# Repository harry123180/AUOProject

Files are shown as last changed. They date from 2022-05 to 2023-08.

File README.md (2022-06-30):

# AUOProject

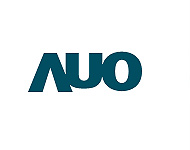
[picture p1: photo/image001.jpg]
   

## 系統架構  
## 如果你想快速開始並設置請參閱[Quick Start Guide](document/Quick%20Start%20Guide.md)

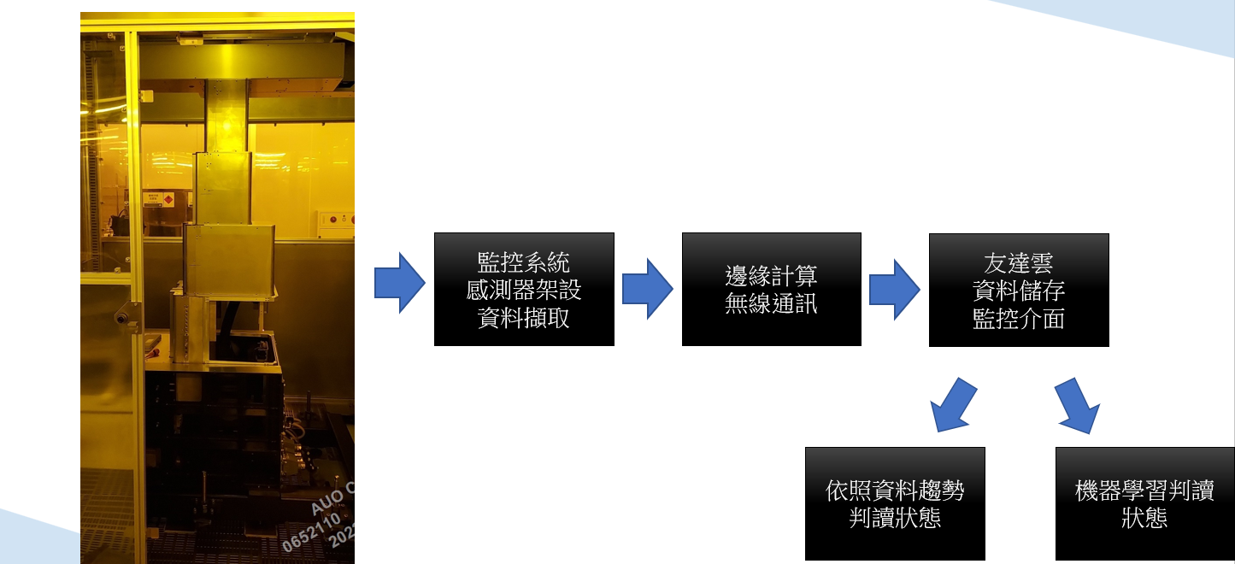
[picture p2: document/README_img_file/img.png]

* 目標開發一個應用於晶圓搬運Robo之Z軸鋼帶壽命監控系統。
* 其系統架構可分成三個部分
  * ## [上游端](document/上游端.md)
    > 該部分主要是感測器、微處理器整合之模組
  * ## [中遊端](document/中遊端.md)
    >該部分主要是基於微處理器上開發整合資料擷取、資料處理、邊緣計算得出特徵指標、無線傳輸等功能
  * ## [下游端](document/下游端.md)
    >該部分主要是終端顯示、資料儲存、人工智慧判斷的部分
* [邊緣計算部分C語言實現API](document/API.md)
* [裝設指南-硬體篇](document/上游端.md)
* [裝設指南-Windows主機篇]
* [裝設指南-InfluxDB篇](document/Install%20InfluxDB%20windows.md)
* [裝設指南-Grafana篇](document/Install%20Grafana%20windows.md)

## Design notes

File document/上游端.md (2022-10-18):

# 上游端    
監控模組3D外觀   
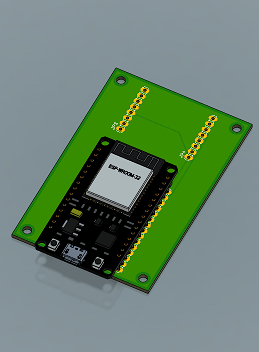
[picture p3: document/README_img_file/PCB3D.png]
  

PCB Layout  
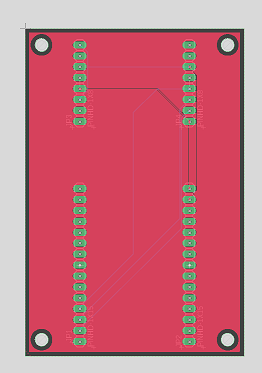
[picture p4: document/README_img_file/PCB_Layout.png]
  
PCB 原理圖  
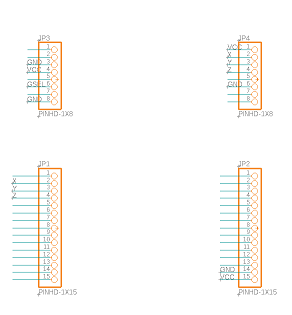
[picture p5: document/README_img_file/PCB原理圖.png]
  
#I/O table  
## FXLN8371Q
|  Pin | Name  | Eescription  | I/O  |
|  ----  | ----  | ----  | ----  |
| 1  | BYP | 內部穩壓器輸出電容連接 |Output |
| 2  | VDD | 電源電壓3.3V |Power |
| 3  | ST | 自我測試<br> • 當 ST 引腳為邏輯高電平時，加速度計進入自檢模式。 <br> • 當 ST 引腳為邏輯低電平時，加速度計進入正常工作模式。 |Input |
| 4  | EN | 電源使能引腳<br>• 當 EN 引腳為邏輯低電平時，加速度計關閉，電流最小<br>• 當 EN 引腳為邏輯高電平時，加速度計功能齊全。 |Input |
| 5  | g-Select | 滿量程範圍選擇： <br>對於部件號 FXLN8361QR1 和 FXLN8371QR1： <br>• 當g-select 引腳為邏輯低電平時，加速度計處於±8 g 模式 <br>• 當g-select 引腳為邏輯高電平時，加速度計處於±2 g 模式<br>對於部件號 FXLN8362QR1 和 FXLN8372QR1：<br>• 當g-select 引腳為邏輯低時，加速度計處於±16 g 模式<br>• 當g-select 引腳為邏輯高電平時，加速度計處於±4 g 模式 |Input |
| 6  | GND | Ground |Ground |
| 7  | GND | Ground |Ground |
| 8  | Z<sub>OUT | Z-axis analog output |Output |
| 9  | Y<sub>OUT | Y-axis analog output |Output |
| 10  | X<sub>OUT | X-axis analog output |Output |
| 11  | NC | 無內部連接，可懸空或連接到 GND |— |
| 12  | NC | 無內部連接，可懸空或連接到 GND |— |
| 13  | NC | 無內部連接，可懸空或連接到 GND |— |  

#FXLN8371Q特性  

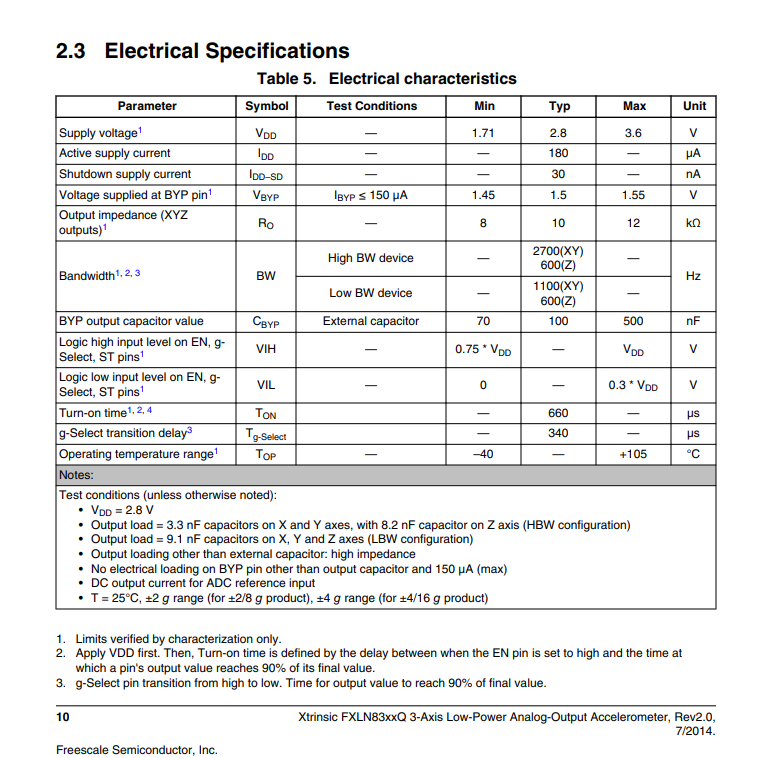
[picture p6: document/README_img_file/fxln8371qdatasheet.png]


##Connection  

|  FXLN8371Q | ESP32  |
|  ----  | ----  |
| X<sub>OUT  | GPIO36 |
| Y<sub>OUT  | GPIO39 |
| Y<sub>OUT  | GPIO34 |
#以下為加速規的重要特性指標
## 靈敏度
> ```X、Y、Z Sensitivity``` : 54mV/g
## 頻寬
|  FXLN8371Q   | BandWidth  |
|  ----  | ----  | 
| X Axis  | 2700Hz |
| Y Axis  | 2700Hz |
| Y Axis  |  600Hz |

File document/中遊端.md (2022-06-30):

#中遊端 MCU EdgeComputing
## 中遊端工作任務主要如下
> * 負責上游感測器的資料擷取
> * 撈取到資料進行邊緣運算
> * 將資料特徵傳輸出去

在本計畫選用ESP32作為中遊節點計算與傳輸的載體
## ESP32-WROOM介紹
|  項目 | 規格  |
|  ----  | ----  |
| 工作電壓  | 3.0V~3.6V |
| 工作電流  | 平均:80mA |
| 供電電流  | 最小:500mA |
| 工作溫度  | -40&deg;C~+85&deg;C|
|封裝尺寸| 18mm &times; 25.5mm &times; 3.1mm|
| Wi-Fi | 支持802.11 b/g/n 協議|
## ESP32-WROOM功能方塊圖
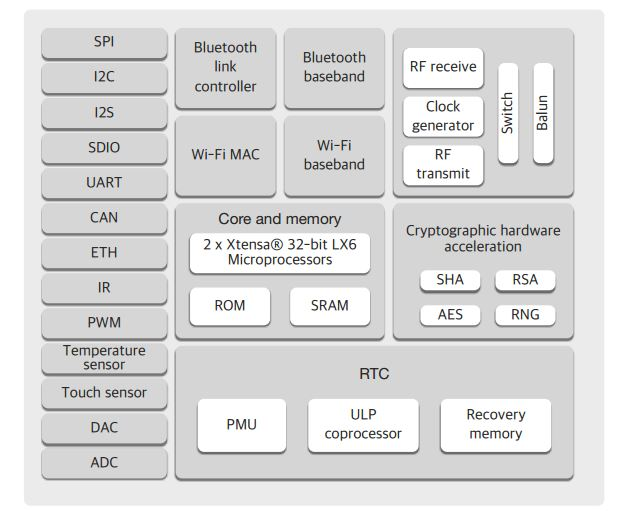
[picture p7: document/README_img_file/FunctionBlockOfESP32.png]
FunctionBlockOfESP32

## 本專案設計遇到注意事項
* ESP32上共有兩個12bit的SARADC分別為ADC1與ADC2
* 其中Wi-Fi也就是無線傳輸功能與ADC2互斥，也就是同時只能運行一個
* 因此ESP32在選擇讀取類比訊號時必須避開ADC2腳位。
* 根據現場量測數據來看，採樣速度須達到5KHz以上，才可以看到我們希望看到的頻率範圍
* 同時對三軸進行5KHz以上速度採樣及FFT轉換，相當重的計算任務
## FreeRTOS對ESP32有良好支援
### [什麼是RTOS?](https://great-vole-c2e.notion.site/ESP32-with-RTOS-08773e8b050648a0af60a7a117fe66ee)一文中有提到，該專案為了解決採樣、邊緣計算、MQTT無線傳輸在MCU上並行執行，採用RTOS架構來編程

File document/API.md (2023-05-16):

# EdgeComputing.h Libary API Document 
## 以下對於本專案使用之指標數學公式進行說明
### ESP對類比式加速規採樣
> ESP的ADC是SARADC具有12bit的解析度(**resolution**)  
> 加速規輸出一電壓訊號時，經由Analog/Digital轉換之後其轉換公式如下  
> $$acceleration = \frac{workvolt}{resolution}*(Numerical-bias)\div sensitivity$$  
> + acceleration: 轉換之加速度值 單位 (g) or (m/s^2) 
> + workvolt: 為ESP32的工作電壓 為3.3V
> + resolution:為ESP32 A/D解析度 12bit=4096
> + Numberical:採樣之後的數值訊號 0~4095之間
> + bias:加速規在0g情況下的數值偏壓
> + sensitivity:加速規的靈敏度 單位 mV/g
### 時域方面
* **平均值**原始數據之平均數值。
>$$\mathrm{Mean}=\frac{1}{n} \sum_{i=1}^{n} x_{i}$$
* **方均根**:原始數據之方均根值，評估訊號振幅。

>$$\mathrm{RMS}=\sqrt{\frac{1}{n} \sum_{i=1}^{n} x_{i}^{2}}$$

* **峰度**:第四中央慣性矩，評估時域訊號中高頻訊號的比例。
>$$ \text { Kurtosis }=\frac{1}{n} \frac{\sum_{i=1}^{n}\left(x_{i}-\mu\right)^{4}}{\sigma^{4}} $$

* **標準差**原始數據之標準差，代表扣除平均值的訊號振幅。
>$$\text { std }=\sqrt{\frac{\sum_{i=1}^{n}\left(x_{i}-\mu\right)^{2}}{n-1}} $$
### 頻域方面
* **頻譜強度總和**:透過在有興趣頻段對PSD做積分即可獲得總功率。
>$$ \text { Total power }=\int_{0}^{f_{s} / 2} S(f) d f $$
* **頻譜強度比例(Ratio of power,ROP)**:此方法主要應用頻寬較大之感測器，頻域訊號依照頻率分段，並以頻段內的總頻譜強度除以頻譜強度總和即為該頻段之頻譜強度比例。
>$$ \text { ROP }=\frac{\int_{f_{1}}^{f_{2}} S(f) d f}{\text { Total power }} $$

### 在ESP32 Program 邊緣計算部分過於複雜，因此獨立編寫一個庫，方便管理及說明
* 整個EdgeComputing庫裡面共有兩個物件可以宣告
1. 第一個是```Func```
2. 第二個是```Computer```

以下是使用範本

```
#include "EdgeComputing.h"
Computer 物件名;
物件名.API();
```
###```Func```為測試用物件，單純實現加法庫。

### ```Computer```為管理指標運算的物件，裡面API說明如下:
> ```float Mean(float* Time_Array);```
> * 輸入參數: 
>>```Time_Array```:時域數據陣列
> * 回傳:
>>```Mean```:平均數

> ```float Std(float* Time_Array,float avg);```
> * 輸入參數: 
>>```Time_Array``` :時域數據陣列  
>>```avg```: 時域數據陣列之平均值
> * 回傳:
>> ```std```:時域數據陣列之標準差

> ```float RMS(float Time_Array);```
> * 輸入參數:
>>```Time_Array```:時域數據陣列
> * 回傳:
>> ```rms```:時域數據陣列之方均根值

> ``` float Kurtosis(float Time_Array,float avg,float std);```
> * 輸入參數:
>> ```Time_Array```:時域數據陣列  
>> ```avg```: 時域數據陣列之平均值  
>> ```std```: 時域數據陣列之標準差
> * 回傳:
>> ```kurtosis```: 時域數據陣列之峰度指標

> ```float Total_Power(float* Freq_Array);```
> * 輸入參數:
>> ```Freq_Array```:經過FFT之後的頻域數據陣列
> * 回傳:
>> ```TP```: 整個頻譜的功率和

> ```float ROP(float* Freq_Array,int Freq_min,int Freq_max,float TP);```
> * 輸入參數:
>> ```Freq_Array```:經過FFT之後的頻域數據陣列
>> ```Freq_min```:有興趣頻段的最小
>> ```Freq_max```:有興趣頻段的最大
> * 回傳:
>> ```rop```: 頻譜強度比例

> ```float Mean_2D(float** Time_Array,float* mean_2d);```
> * 輸入參數:
>> ```Time_Array```:二維時域數據[軸][採樣buffer長度]  
>> ```mean_2d```:空的一維陣列，用以存放各軸計算結果，長度為軸數
> * 回傳:
>> ```mean_2d```:計算好的各軸計算結果

> ```float Std_2D(float** Time_Array,float* avg,float* std_2d);```
> * 輸入參數:
>> ```Time_Array```:二維時域數據[軸][採樣buffer長度]  
>> ```avg```:一維陣列，存放各軸平均值  
>> ```std_2d```:空的一維陣列，用以存放各軸計算結果，長度為軸數
> * 回傳:
>> ```std_2d```:計算好的各軸計算std結果

> ```float RMS_2D(float** Time_Array,float* rms_2d);```
> * 輸入參數:
>> ```Time_Array```:二維時域數據[軸][採樣buffer長度]  
>> ```rms_2d```:空的一維陣列，用以存放各軸計算結果，長度為軸數
> * 回傳:
>> ```rms_2d```:計算好的各軸計算rms結果
> ```float Kurtosis_2D(float** Time_Array,float* avg,float* std,float* kurtosis_2d);```
> * 輸入參數:
>> ```Time_Array```:二維時域數據[軸][採樣buffer長度]  
>> ```avg```:一維陣列，存放各軸平均值  
>> ```std```:一維陣列，存放各軸標準差  
>> ```kurtosis_2d```:空的一維陣列，用以存放各軸計算結果，長度為軸數
> * 回傳:
>> ```kurtosis_2d```:計算好的各軸計算kurtosis結果

> ```float Total_Power_2D(float** Freq_Array,float* total_power_2d);```
> * 輸入參數:
>>```Freq_Array```:經過FFT之二維頻域數據[軸][採樣buffer長度]  
>>```total_power_2d```:空的一維陣列，用以存放各軸計算結果，長度為軸數
> * 回傳:
>>```total_power_2d```:計算好的各軸計算TP結果

> ```float ROP_2D(float** Freq_Array,int* Freq_min,int* Freq_max,float* TP,float* rop_2d);```
> * 輸入參數:
>>```Freq_Array```:經過FFT之二維頻域數據[軸][採樣buffer長度]  
>>```Freq_min```:存放各軸有興趣頻段最小值之一維陣列 
>>```Freq_max```:存放各軸有興趣頻段最大值之一維陣列 
>>```rop_2d```:空的一維陣列，用以存放各軸計算結果，長度為軸數
> * 回傳:
>>```rop_2d```:計算好的各軸計算rop結果

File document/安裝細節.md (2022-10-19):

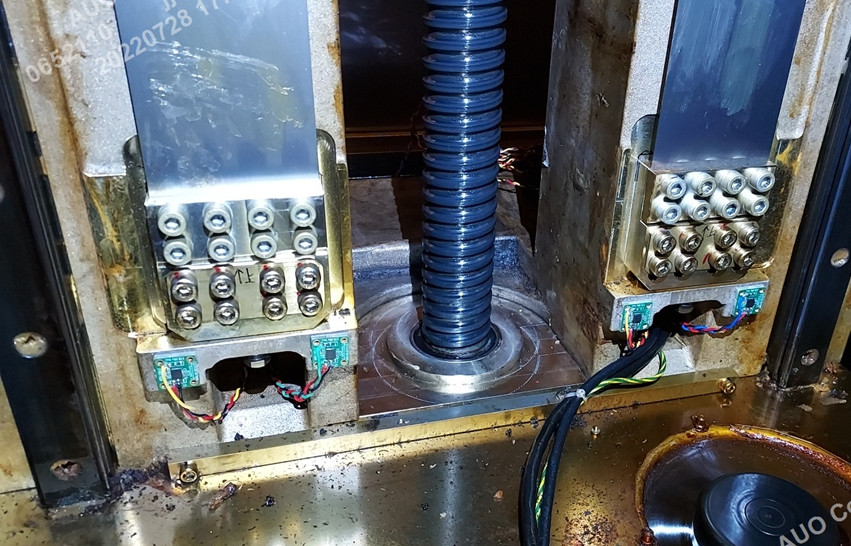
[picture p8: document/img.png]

目前安裝的號數    
3號從端X軸   
1號從端X、Y、Z軸
2號 3軸數位加速規MPU6050
4號 應變規

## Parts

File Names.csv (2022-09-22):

No | Name | Country
1 | Alex | India
2 | Ben | USA
3 | Shri Ram | India
4 | Smith | USA
5 | Yuva Raj | India
No | Name | Country
1 | Alex | India
2 | Ben | USA
3 | Shri Ram | India
4 | Smith | USA
5 | Yuva Raj | India
No | Name | Country
1 | Alex | India
2 | Ben | USA
3 | Shri Ram | India
4 | Smith | USA
5 | Yuva Raj | India
No | Name | Country
1 | Alex | India
2 | Ben | USA
3 | Shri Ram | India
4 | Smith | USA
5 | Yuva Raj | India

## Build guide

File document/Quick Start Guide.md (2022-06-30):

# Quick Start Guide

## 首先將這份.zip檔案送去PCB廠家製作[檔案連結](https://github.com/harry123180/AUOProject/blob/cd63b463207a05c479944efaf1438e0ff1443a89/MCU-Sensor-dev-v16_2022-06-02)
* ### 此專案開發是送[ICBOX艾斯霸](https://icbox.com.tw/)公司進行洗板
>檔案名稱: MCU-Sensor-dev-v16_2022-06-02  
>製程:     FR-4 黑底白字 1.6MM板厚 有鉛噴錫 1OZ銅箔  
>數量:    10pcs  
>報價:    NT$800 含稅
* ### MCU 開發IDE [Arduino IDE 1.8.16](https://www.arduino.cc/en/software)

* ### MCU 型號 :ESP32-WROOM-32 [購買連結](https://shopee.tw/ESP32S%E5%96%AE%E7%89%87%E6%A9%9F30pin%EF%BC%8EDEVKIT-V1%E9%96%8B%E7%99%BC%E6%9D%BFWiFi%E8%97%8D%E7%89%99ioT%E7%89%A9%E8%81%AF%E7%B6%B2%E9%9B%99%E6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)

* ### 使用Arudino IDE開啟[這個資料夾](https://github.com/harry123180/AUOProject/blob/cd63b463207a05c479944efaf1438e0ff1443a89/upstream/ESP_Program/3Axis_FFT_FXLN8371Q_Serial_MakeSure)將程式燒入

* ### 參照這篇在主機上安裝[InfluxDB](https://docs.influxdata.com/influxdb/v2.2/install/?t=Windows)
* ### 使用Python腳本來連結MCU傳入的data至InfluxDB 範例語法如下
``` 
from datetime import datetime

from influxdb_client import InfluxDBClient, Point, WritePrecision
from influxdb_client.client.write_api import SYNCHRONOUS

# You can generate an API token from the "API Tokens Tab" in the UI
token = "1W7iej02NfAdH6xYrU1gjIvgavP7XI0enWeyUUYDRbO4OWI1ETXYCVVdbjBmfM3bYEIf8A-cpZ757FKnKyNhCA=="
org = "harry"
bucket = "b1"

with InfluxDBClient(url="http://localhost:8086", token=token, org=org) as client:
    write_api = client.write_api(write_options=SYNCHRONOUS)

    data = "mem,host=host1 test=23.43234543 "
    write_api.write(bucket, org, data)
    data = "mem,host=host1 test1=23.43234543 "
    write_api.write(bucket, org, data)

```
* ### 參照這篇在主機上安裝[Grafana](document/Install Grafana windows.md)
### Flux語法在Grafana上
* Example  

```
  from(bucket: "testDB")
  |> range(start: -5h, stop: -1s)
  |> filter(fn: (r) => r["_measurement"] == "mem" and r["_field"] == "ch2")
  |> aggregateWindow(every: v.windowPeriod, fn: mean, createEmpty: false)
  |> yield()  
  ```

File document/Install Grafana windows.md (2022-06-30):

# 在Windows安裝Grfana
## 主要參照這篇[在Windows安裝Grafana](https://grafana.com/docs/grafana/latest/installation/windows/)

# Grafana初始設定
## 預設帳號密碼
> User: ```admin ```  
> Password: ```admin```  

* Grafana的預設內網埠口在3000，因此要訪問的話在瀏覽器輸入[http://localhost:3000/](http://localhost:3000/)就可以訪問了。
* 如果要在同一個區網以其他設備瀏覽，必須在Grafana運行的機器上將防火牆勾選允許訪問，操作如[該篇](https://wiki.mcneel.com/zh-tw/zoo/window7firewall)
# 至此應該已經成功運行Grafana
## 設定資料源
* 第一步在Grafana UI上點選設定資料源  
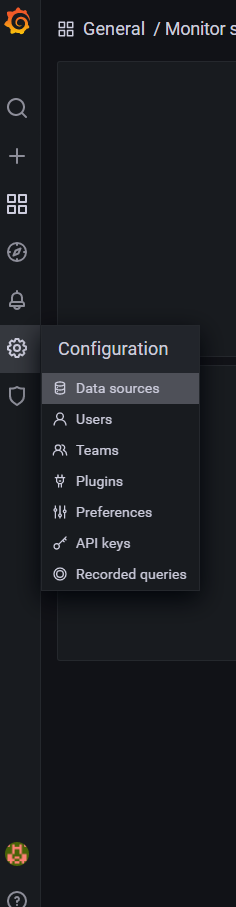
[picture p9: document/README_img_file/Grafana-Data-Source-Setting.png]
新增資料源
  
* 第二步選擇InfluxDB  
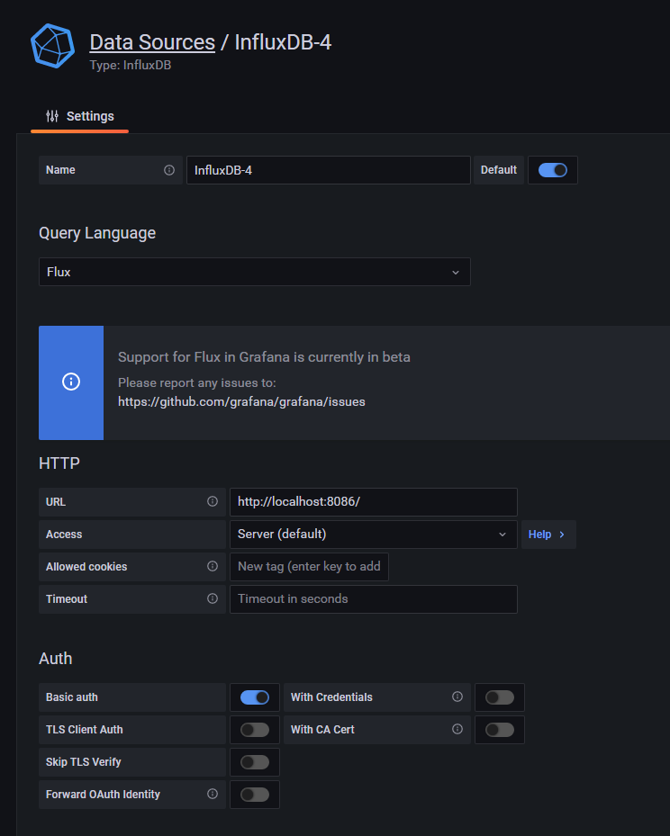
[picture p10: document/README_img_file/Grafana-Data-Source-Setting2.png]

* 第三步 頁面往下滾，將InfluxDB端設定的資料填入，如Bucket名字、Organization token之類的訊息
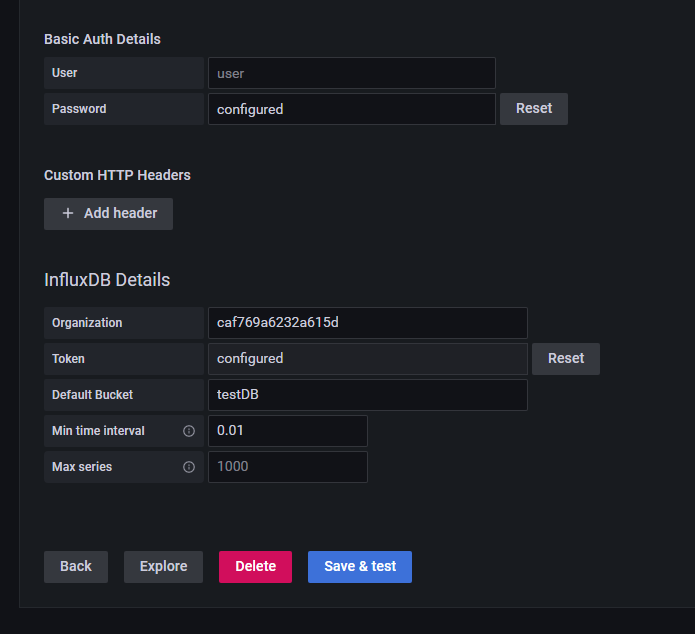
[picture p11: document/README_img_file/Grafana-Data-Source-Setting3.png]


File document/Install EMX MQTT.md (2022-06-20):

# Install EMQX MQTT Server

## [Document](https://www.emqx.io/docs/en/v3.0/install.html#centos)

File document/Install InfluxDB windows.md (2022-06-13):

# 在Windows 安裝InfluxDB

## 主要參照[這篇Install InfluxDB](https://docs.influxdata.com/influxdb/v2.2/install/?t=Windows)

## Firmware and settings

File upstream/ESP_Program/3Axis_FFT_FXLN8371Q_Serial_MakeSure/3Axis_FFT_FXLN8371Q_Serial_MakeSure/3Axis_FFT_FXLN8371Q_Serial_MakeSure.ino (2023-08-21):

#include <Wire.h>
#include <PubSubClient.h>
#include "FFT.h"
#include <math.h>
// Serial Send Variable
double Mean_[3] = {0};
double Std_[3] = {0};
double RMS_[3] = {0};
double Kurtosis_[3] = {0};
double tp_[3] = {0};
/* EdegComputing宣告*/
#include "EdgeComputing.h"
#define axis_num  3//總共有三軸
short int sensitivity = 54;
#define FFT_N 1024 // Must be a power of 2
Computer EC(FFT_N,axis_num,sensitivity);

//****FFT 必須的變數****//
int Sampling_Rate =1000;//5500
short int TimerRef = 1000000/Sampling_Rate;
const float TOTAL_TIME = 0.1861; // This is equal to FFT_N/sampling_freq
float fft_input0[FFT_N];
float fft_output0[FFT_N];
float fft_input1[FFT_N];
float fft_output1[FFT_N];
float fft_input2[FFT_N];
float fft_output2[FFT_N];
float freq_mag[axis_num][FFT_N/2];
int ORG_signal[axis_num][FFT_N];
float Time_Array[axis_num][FFT_N];

char print_buf[500];
bool flag0 =false;
bool flag1 =false;
bool flag2 =false;
bool EC_State=false;
const float num2g = 0.01491970486;
//***FXLN變數****//
const short int FXLN8371Q_X = 36;
const short int FXLN8371Q_Y = 39;
const short int FXLN8371Q_Z = 34;
//****計時中斷的變數****//
int t0Counter=0;
int t1Counter=0;
int t2Counter=0;
hw_timer_t * timer_0 = NULL;//宣告一個指向硬體計時器的變量
hw_timer_t * timer_1 = NULL;
hw_timer_t * timer_2 = NULL;
portMUX_TYPE timerMux_0 = portMUX_INITIALIZER_UNLOCKED;//使用它來處理主循環與ISR之間的同步
portMUX_TYPE timerMux_1 = portMUX_INITIALIZER_UNLOCKED;
portMUX_TYPE timerMux_2 = portMUX_INITIALIZER_UNLOCKED;
//influxdb設定
#if defined(ESP32)
#include <WiFiMulti.h>
WiFiMulti wifiMulti;
#define DEVICE "ESP32"
#elif defined(ESP8266)
#include <ESP8266WiFiMulti.h>
ESP8266WiFiMulti wifiMulti;
#define DEVICE "ESP8266"
#endif
#include <WiFiManager.h>
#include <InfluxDbClient.h>
#include <InfluxDbCloud.h>
#define INFLUXDB_URL "http://125.229.142.15:9453"
// InfluxDB v2 server or cloud API token (Use: InfluxDB UI -> Data -> API Tokens -> Generate API Token)
#define INFLUXDB_TOKEN "VLJI0v-iKBTAmclC9KWPYEwN4swa6mITR-LJK1uw3c1_LDzwgroQ-eliFQcq1-YJc6G1FdL_ULa-z2U1aKe5mw=="
// InfluxDB v2 organization id (Use: InfluxDB UI -> User -> About -> Common Ids )
#define INFLUXDB_ORG "K1082"
// InfluxDB v2 bucket name (Use: InfluxDB UI ->  Data -> Buckets)
#define INFLUXDB_BUCKET "test"
#define TZ_INFO "GMT-8"
InfluxDBClient client(INFLUXDB_URL, INFLUXDB_ORG, INFLUXDB_BUCKET, INFLUXDB_TOKEN, InfluxDbCloud2CACert);
Point sensor("mem6");
WiFiManager wm;
//octivae band設定
//*******************octave band壓縮****************//
const int NUM_BANDS = 6;
const float CENTER_FREQS[NUM_BANDS] = {16,    31.5, 63,  125, 250,  500};
const int LOWER_BOUNDS[NUM_BANDS] =   {11,    23,   45,  89,  178,  356};
const int UPPER_BOUNDS[NUM_BANDS] =   {22,    44,   88,  177, 355,  511 };
 //*******Task任務內容*********//
void taskOne( void * parameter ){
  /*
   * 並將數值存入fft_signal
   * 袴
   */
  while(1){
        //sprintf(print_buf,"%d %d %d",flag0,flag1,flag2);
        
        if(flag0 && flag1 && flag2){
          Serial.println(flag0);
          float max_magnitude[axis_num] = {0};
          float fundamental_freq[axis_num] = {0};
          EC.Convert_2d(ORG_signal,Time_Array);
          EC.Mean_2D(Time_Array,Mean_);
          EC.Std_2D(Time_Array,Mean_,Std_);          
          EC.RMS_2D(Time_Array,RMS_);          
          EC.Kurtosis_2D(Time_Array,Mean_,Std_,Kurtosis_);
          flag0 = false;
          flag1 = false;
          flag2 = false;
          EC_State = true;
          fft_config_t *real_fft_plan_0 = fft_init(FFT_N, FFT_REAL, FFT_FORWARD, fft_input0, fft_output0);
          fft_config_t *real_fft_plan_1 = fft_init(FFT_N, FFT_REAL, FFT_FORWARD, fft_input1, fft_output1);
          fft_config_t *real_fft_plan_2 = fft_init(FFT_N, FFT_REAL, FFT_FORWARD, fft_input2, fft_output2);
          for (int k = 0 ; k < FFT_N ; k++){
            real_fft_plan_0->input[k] = (float)Time_Array[0][k];//將fft_signal填入輸入槽位
            real_fft_plan_1->input[k] = (float)Time_Array[1][k];//將fft_signal填入輸入槽位
            real_fft_plan_2->input[k] = (float)Time_Array[2][k];//將fft_signal填入輸入槽位  
          }
          fft_execute(real_fft_plan_0);
          fft_execute(real_fft_plan_1);
          fft_execute(real_fft_plan_2);
          for (int k = 1 ; k < real_fft_plan_1->size / 2 ; k++){
            //The real part of a magnitude at a frequency is followed by the corresponding imaginary part in the output
            freq_mag[0][k] = sqrt(pow(real_fft_plan_0->output[2*k],2) + pow(real_fft_plan_0->output[2*k+1],2))/1;
            freq_mag[1][k] = sqrt(pow(real_fft_plan_1->output[2*k],2) + pow(real_fft_plan_1->output[2*k+1],2))/1;
            freq_mag[2][k] = sqrt(pow(real_fft_plan_2->output[2*k],2) + pow(real_fft_plan_2->output[2*k+1],2))/1;
            float freq = k*1.0/TOTAL_TIME;
            
            if(freq_mag[0][k] > max_magnitude[0]){
                max_magnitude[0] = freq_mag[0][k];
                fundamental_freq[0] = freq;
            }
            if(freq_mag[1][k] > max_magnitude[1]){
                max_magnitude[1] = freq_mag[1][k];
                fundamental_freq[1] = freq;
            }   
            if(freq_mag[2][k] > max_magnitude[2]){
                max_magnitude[2] = freq_mag[2][k];
                fundamental_freq[2] =freq;
            }        
          }                    
          flag0 = false;//將fft_sginal填充完畢 flag復位
          flag1 = false;
          flag2 = false;          
          fft_destroy(real_fft_plan_0);//釋放fft記憶體
          fft_destroy(real_fft_plan_1);
          fft_destroy(real_fft_plan_2);   
          EC.Total_Power_2D(freq_mag,tp_); 
          //sprintf(print_buf,"%d %.2f %.2f %.2f %.2f %.2f %.2f %.2f %.2f %.2f %.1f %.1f %.1f %.1f %.1f %.1f %.1f %.1f %.1f\n",1,Mean_[0],Mean_[1],Mean_[2],Std_[0],Std_[1],Std_[2],RMS_[0],RMS_[1],RMS_[2],Kurtosis_[0],Kurtosis_[1],Kurtosis_[2],fundamental_freq[0],fundamental_freq[1],fundamental_freq[2],tp_[0],tp_[1],tp_[2]);
          //sprintf(print_buf,"%.1f %.1f %.1f\n",Mean_[0],Mean_[1],Mean_[2]);
          //Serial.print(print_buf);
          //for(int i =0 ;i<1024;i++){
            //Serial.println(Time_Array[2][i]);
          //}
        }
       
  }
  Serial.println("Ending task 1");
  vTaskDelete( NULL );
}

void IRAM_ATTR onTimer_0() {
  //portEXIT_CRITICAL_ISR(&timerMux_0);
  ORG_signal[0][t0Counter] = analogRead(FXLN8371Q_X)-2300;
  t0Counter++;
  
  if(t0Counter>FFT_N){
    t0Counter=0;
    flag0 = true; //把flag打開 通知fft可以進行了
  }
}
void IRAM_ATTR onTimer_1() {
  ORG_signal[1][t1Counter] = analogRead(FXLN8371Q_Y);
  t1Counter++;
  if(t1Counter>FFT_N){
    t1Counter=0;
    flag1 = true; //把flag打開 通知fft可以進行了
  }
}
void IRAM_ATTR onTimer_2() {
  ORG_signal[2][t2Counter] = analogRead(FXLN8371Q_Z);
  t2Counter++;
  if(t2Counter>FFT_N){
    t2Counter=0;
    flag2 = true; //把flag打開 通知fft可以進行了
  }
}
void compressOctaveBand(float* data_fft, float* output) {
  for (int i = 0; i < NUM_BANDS; i++) {
    float sum = 0;
    for (int j = LOWER_BOUNDS[i]; j <= UPPER_BOUNDS[i]; j++) {
      sum += data_fft[j];
    }
    output[i] = sum;
  }
}
void setup() {
  Serial.begin(115200);
  delay(1000);
  //wm.resetSettings();
  bool res;
  res = wm.autoConnect("AutoConnectAP","password");
  Serial.print("Connecting to wifi");
  if(!res) {
          Serial.println("Failed to connect");
          // ESP.restart();
      } 
  else {
          //if you get here you have connected to the WiFi    
          Serial.println("connected...yeey :)");
      }
  // Add tags
  sensor.addTag("device", DEVICE);
  timeSync(TZ_INFO, "pool.ntp.org", "time.nis.gov");
  if (client.validateConnection()) {
    Serial.print("Connected to InfluxDB: ");
    Serial.println(client.getServerUrl());
  } else {
    Serial.print("InfluxDB connection failed: ");
    Serial.println(client.getLastErrorMessage());
  }
  delay(1000);
  //******計時中斷設定******//
  //為了達到指定sampling rate//
  timer_0 = timerBegin(0, 80, true);
  timerAttachInterrupt(timer_0, &onTimer_0, true);
  timerAlarmWrite(timer_0, TimerRef, true);
  timerAlarmEnable(timer_0);
  
  timer_1 = timerBegin(1, 80, true);
  timerAttachInterrupt(timer_1, &onTimer_1, true);
  timerAlarmWrite(timer_1, TimerRef, true);
  timerAlarmEnable(timer_1);
  
  timer_2 = timerBegin(2, 80, true);
  timerAttachInterrupt(timer_2, &onTimer_2, true);
  timerAlarmWrite(timer_2, TimerRef, true);
  timerAlarmEnable(timer_2);
  
  //
  //Task宣告及初期設定
  xTaskCreatePinnedToCore(
  taskOne, //本任務實際對應的Function
  "TaskOne", //任務名稱（自行設定）
  10000, //所需堆疊空間（常用10000）
  NULL, //輸入值
  0, //優先序：0為最低，數字越高代表越優先
  NULL, //對應的任務handle變數
  tskNO_AFFINITY); //指定執行核心編號（0、1或tskNO_AFFINITY：系統指定）
}
 
void loop(){
  if(flag0 && flag1 && flag2){
    float max_magnitude[axis_num] = {0};
          float fundamental_freq[axis_num] = {0};
          EC.Convert_2d(ORG_signal,Time_Array);
          EC.Mean_2D(Time_Array,Mean_);
          EC.Std_2D(Time_Array,Mean_,Std_);          
          EC.RMS_2D(Time_Array,RMS_);          
          EC.Kurtosis_2D(Time_Array,Mean_,Std_,Kurtosis_);
          /**/
          sensor.addField("MeanX", Mean_[0]);
          sensor.addField("StdX", Std_[0]); 
          sensor.addField("KurtosisX", Kurtosis_[0]); 
          sensor.addField("MeanY", Mean_[1]);
          sensor.addField("StdY", Std_[1]); 
          sensor.addField("KurtosisY", Kurtosis_[1]); 
          sensor.addField("MeanZ", Mean_[2]);
          sensor.addField("StdZ", Std_[2]); 
          sensor.addField("KurtosisZ", Kurtosis_[2]); 
          flag0 = false;
          flag1 = false;
          flag2 = false;
          EC_State = true;
          fft_config_t *real_fft_plan_0 = fft_init(FFT_N, FFT_REAL, FFT_FORWARD, fft_input0, fft_output0);
          fft_config_t *real_fft_plan_1 = fft_init(FFT_N, FFT_REAL, FFT_FORWARD, fft_input1, fft_output1);
          fft_config_t *real_fft_plan_2 = fft_init(FFT_N, FFT_REAL, FFT_FORWARD, fft_input2, fft_output2);
          for (int k = 0 ; k < FFT_N ; k++){
            real_fft_plan_0->input[k] = (float)Time_Array[0][k];//將fft_signal填入輸入槽位
            real_fft_plan_1->input[k] = (float)Time_Array[1][k];//將fft_signal填入輸入槽位
            real_fft_plan_2->input[k] = (float)Time_Array[2][k];//將fft_signal填入輸入槽位  
          }
          fft_execute(real_fft_plan_0);
          fft_execute(real_fft_plan_1);
          fft_execute(real_fft_plan_2);
          for (int k = 1 ; k < real_fft_plan_1->size / 2 ; k++){
            //The real part of a magnitude at a frequency is followed by the corresponding imaginary part in the output
            freq_mag[0][k] = sqrt(pow(real_fft_plan_0->output[2*k],2) + pow(real_fft_plan_0->output[2*k+1],2))/1;
            freq_mag[1][k] = sqrt(pow(real_fft_plan_1->output[2*k],2) + pow(real_fft_plan_1->output[2*k+1],2))/1;
            freq_mag[2][k] = sqrt(pow(real_fft_plan_2->output[2*k],2) + pow(real_fft_plan_2->output[2*k+1],2))/1;
            float freq = k*1.0/TOTAL_TIME;
            
            if(freq_mag[0][k] > max_magnitude[0]){
                max_magnitude[0] = freq_mag[0][k];
                fundamental_freq[0] = freq;
            }
            if(freq_mag[1][k] > max_magnitude[1]){
                max_magnitude[1] = freq_mag[1][k];
                fundamental_freq[1] = freq;
            }   
            if(freq_mag[2][k] > max_magnitude[2]){
                max_magnitude[2] = freq_mag[2][k];
                fundamental_freq[2] =freq;
            }        
          }  
          float compressed[NUM_BANDS] = {};
          compressOctaveBand(freq_mag[2] , compressed);  
           for(int sender_indx =0;sender_indx<NUM_BANDS;sender_indx++){
             sensor.addField(String(CENTER_FREQS[sender_indx])+"Hz",compressed[sender_indx]);                  
             //Serial.print(compressed[sender_indx]);
             //Serial.print(" ");
             //Serial.println(String(CENTER_FREQS[sender_indx])+"Hz");
          }                  
          flag0 = false;//將fft_sginal填充完畢 flag復位
          flag1 = false;
          flag2 = false;          
          fft_destroy(real_fft_plan_0);//釋放fft記憶體
          fft_destroy(real_fft_plan_1);
          fft_destroy(real_fft_plan_2);   
          EC.Total_Power_2D(freq_mag,tp_); 
          // Serial.println(millis() - start_time );
          //Serial.print("Writing: ");
          //Serial.println(sensor.toLineProtocol());
        
          Serial.println(wm.getWLStatusString());
          if (!client.writePoint(sensor)) {
            Serial.print("InfluxDB write failed: ");
            Serial.println(client.getLastErrorMessage());
          }
  }
  delay(1);
}
//                    開發By蘇泓舉
//                    2022.6.30 Final Version
//                       _oo0oo_
//                      o8888888o
//                      88" . "88
//                      (| -_- |)
//                      0\  =  /0
//                    ___/`---'\___
//                  .' \\|     |// '.
//                 / \\|||  :  |||// \
//                / _||||| -:- |||||- \
//               |   | \\\  -  /// |   |
//               | \_|  ''\---/''  |_/ |
//               \  .-\__  '-'  ___/-. /
//             ___'. .'  /--.--\  `. .'___
//          ."" '<  `.___\_<|>_/___.' >' "".
//         | | :  `- \`.;`\ _ /`;.`/ - ` : | |
//         \  \ `_.   \_ __\ /__ _/   .-` /  /
//     =====`-.____`.___ \_____/___.-`___.-'=====
//                       `=---='
//
//
//     ~~~~~~~~~~~~~~~~~~~~~~~~~~~~~~~~~~~~~~~~~~~
//
//               佛祖保佑         永無BUG
//
//
//

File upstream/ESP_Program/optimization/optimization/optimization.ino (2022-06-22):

#include <Wire.h>
#include <WiFi.h>
#include <PubSubClient.h>
#include "FFT.h"
#include <math.h>
//****MQTT 必需的變數***//
const char* ssid = "HUNGCHU";
const char* password = "datadata";
const char* mqtt_server = "lwcjacky.myds.me";//免註冊MQTT伺服器
const unsigned int mqtt_port = 18084;
#define MQTT_USER               "test"             //本案例未使用
#define MQTT_PASSWORD           "vcAnn8GZ"         //本案例未使用
WiFiClient espClient; 
PubSubClient client(espClient);
/* EdegComputing宣告*/
#include "EdgeComputing.h"
#define axis_num  3//總共有三軸
short int sensitivity = 54;
#define FFT_N 1024 // Must be a power of 2
Computer EC(FFT_N,axis_num,sensitivity);

//****FFT 必須的變數****//
int Sampling_Rate =5500;
short int TimerRef = 1000000/Sampling_Rate;
const float TOTAL_TIME = FFT_N/Sampling_Rate; // This is equal to FFT_N/sampling_freq
float fft_input0[FFT_N];
float fft_output0[FFT_N];
float fft_input1[FFT_N];
float fft_output1[FFT_N];
float fft_input2[FFT_N];
float fft_output2[FFT_N];
float max_magnitude = 0;
float fundamental_freq = 0;
int ORG_signal[axis_num][FFT_N];
float Time_Array[axis_num][FFT_N];

char print_buf[500];
bool flag0 =false;
bool flag1 =false;
bool flag2 =false;

const float num2g = 0.01491970486;
//***FXLN變數****//
const short int FXLN8371Q_X = 36;
const short int FXLN8371Q_Y = 39;
const short int FXLN8371Q_Z = 34;
//****計時中斷的變數****//
int t0Counter=0;
int t1Counter=0;
int t2Counter=0;
hw_timer_t * timer_0 = NULL;//宣告一個指向硬體計時器的變量
hw_timer_t * timer_1 = NULL;
hw_timer_t * timer_2 = NULL;
portMUX_TYPE timerMux_0 = portMUX_INITIALIZER_UNLOCKED;//使用它來處理主循環與ISR之間的同步
portMUX_TYPE timerMux_1 = portMUX_INITIALIZER_UNLOCKED;
portMUX_TYPE timerMux_2 = portMUX_INITIALIZER_UNLOCKED;


 //*******Task任務內容*********//
void taskOne( void * parameter ){
  /*taskone做i2c 讀取adxl的數值 
   * 並將數值存入fft_signal
   * 袴
   */
  while(1){
        if (!client.connected()) {
            reconnect();
          }
        client.loop();
        EC.Convert_2d(ORG_signal,Time_Array);
        if(flag0 && flag1 && flag2){
          double Mean_[axis_num] = {0};
          EC.Mean_2D(Time_Array,Mean_);
          double Std_[axis_num] = {0};
          EC.Std_2D(Time_Array,Mean_,Std_);
          double RMS_[axis_num] = {0};
          EC.RMS_2D(Time_Array,RMS_);
          double Kurtosis_[axis_num] = {0};
          EC.Kurtosis_2D(Time_Array,Mean_,Std_,Kurtosis_);
          //sprintf(print_buf,"%f %f %f\n", RMS_[0], RMS_[1] ,RMS_[2]);
          //Serial.println(print_buf);
          char Mean_String[axis_num][8];
          char Std_String[axis_num][8];
          char RMS_String[axis_num][8];
          char Kurtosis_String[axis_num][8];
          for(int c=0;c<axis_num;c++){
          //  Mean_String[c] = String(Mean_[c],3);
          dtostrf(Mean_[c], 1, 2, Mean_String[c]);
          dtostrf(Std_[c], 1, 2, Std_String[c]);         
          dtostrf(RMS_[c], 1, 2, RMS_String[c]);        
          dtostrf(Kurtosis_[c], 1, 2, Kurtosis_String[c]);         
          }
          client.publish("sensor/0/x/mean", Mean_String[0]);
          client.publish("sensor/0/y/mean", Mean_String[1]);
          client.publish("sensor/0/z/mean", Mean_String[2]);
          client.publish("sensor/0/x/std", Std_String[0]);
          client.publish("sensor/0/y/std", Std_String[1]);
          client.publish("sensor/0/z/std", Std_String[2]);
          client.publish("sensor/0/x/rms", RMS_String[0]);
          client.publish("sensor/0/y/rms", RMS_String[1]);
          client.publish("sensor/0/z/rms", RMS_String[2]);
          client.publish("sensor/0/x/kurtosis", Kurtosis_String[0]);
          client.publish("sensor/0/y/kurtosis", Kurtosis_String[1]);
          client.publish("sensor/0/z/kurtosis", Kurtosis_String[2]);
          flag0 = false;
          flag1 = false;
          flag2 = false;
          fft_config_t *real_fft_plan_0 = fft_init(FFT_N, FFT_REAL, FFT_FORWARD, fft_input0, fft_output0);
          fft_config_t *real_fft_plan_1 = fft_init(FFT_N, FFT_REAL, FFT_FORWARD, fft_input1, fft_output1);
          fft_config_t *real_fft_plan_2 = fft_init(FFT_N, FFT_REAL, FFT_FORWARD, fft_input2, fft_output2);
          for (int k = 0 ; k < FFT_N ; k++){
            real_fft_plan_0->input[k] = (float)Time_Array[0][k];//將fft_signal填入輸入槽位
            real_fft_plan_1->input[k] = (float)Time_Array[1][k];//將fft_signal填入輸入槽位
            real_fft_plan_2->input[k] = (float)Time_Array[2][k];//將fft_signal填入輸入槽位  
          }
          fft_execute(real_fft_plan_0);
          fft_execute(real_fft_plan_1);
          fft_execute(real_fft_plan_2);
          for (int k = 1 ; k < real_fft_plan_1->size / 2 ; k++){
            //The real part of a magnitude at a frequency is followed by the corresponding imaginary part in the output
            float mag_0 = sqrt(pow(real_fft_plan_0->output[2*k],2) + pow(real_fft_plan_0->output[2*k+1],2))/1;
            float mag_1 = sqrt(pow(real_fft_plan_1->output[2*k],2) + pow(real_fft_plan_1->output[2*k+1],2))/1;
            float mag_2 = sqrt(pow(real_fft_plan_2->output[2*k],2) + pow(real_fft_plan_2->output[2*k+1],2))/1;
            float freq = k*1.0/TOTAL_TIME;
            //sprintf(print_buf,"%.1f %.1f %.1f",mag_0,mag_1,mag_2);
            //Serial.println(print_buf);
            //sprintf(print_buf,"%.1f ",freq);
            //Serial.println(print_buf);
            if(mag_1 > max_magnitude){
                max_magnitude = mag_1;
                fundamental_freq = freq;
            }     
          }
          
          sprintf(print_buf,"Fundamental Freq : %f Hz\t Mag: %f g\n", fundamental_freq, (max_magnitude/10000)*2/FFT_N);
          Serial.println(print_buf);
          flag0 = false;//將fft_sginal填充完畢 flag復位
          flag1 = false;
          flag2 = false; 
          fft_destroy(real_fft_plan_0);//釋放fft記憶體
          fft_destroy(real_fft_plan_1);
          fft_destroy(real_fft_plan_2);    
        }
       
  }
  Serial.println("Ending task 1");
  vTaskDelete( NULL );
}
void IRAM_ATTR onTimer_0() {
  //portEXIT_CRITICAL_ISR(&timerMux_0);
  t0Counter++;
  
  ORG_signal[0][t0Counter] = analogRead(FXLN8371Q_X);
  if(t0Counter>FFT_N){
    t0Counter=0;
    //Serial.println("Reset  T0 Sampling Flag");
    flag0 = true; //把flag打開 通知fft可以進行了
  }
  //portEXIT_CRITICAL_ISR(&timerMux_0);
}
void IRAM_ATTR onTimer_1() {
  //portEXIT_CRITICAL_ISR(&timerMux_1);
  t1Counter++;
  //Serial.println("DO onTimer_1");
  ORG_signal[1][t1Counter] = analogRead(FXLN8371Q_Y);
  if(t1Counter>FFT_N){
    //Serial.println("Reset T1 Sampling Flag");
    t1Counter=0;
    flag1 = true; //把flag打開 通知fft可以進行了
  }
  //portEXIT_CRITICAL_ISR(&timerMux_1);
}
void IRAM_ATTR onTimer_2() {
  //portEXIT_CRITICAL_ISR(&timerMux_2);
  t2Counter++;
  ORG_signal[2][t2Counter] = analogRead(FXLN8371Q_Z);
  if(t2Counter>FFT_N){
    t2Counter=0;
    flag2 = true; //把flag打開 通知fft可以進行了
  }
  //portEXIT_CRITICAL_ISR(&timerMux_2);
}
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

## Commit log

2021-10-19 updata
    更新UI部件
    測試MCU通訊速率
2021-10-19 10.19
    主介面 function GET_DATA新增了print(哈囉)
2022-04-23 upload_pyfilee
    新增處理資料的Pyfile
2022-04-25 FFTisRight
    pulse Sampling rate =256Hz!
2022-06-02 MQTT功能完善
2022-06-17 change
    驗算解析度
2022-07-04 數據比較
2022-10-19 Gen2PyFile
    二代機上盒Py檔案上傳
    位置在下游裡面
2022-10-19 峰值計算錯誤
    發現0/0會溢位 多加了if判斷修正0/0情況 修改內容再EdegComputing.cpp裡面
    3個從端都改
2022-12-12 更新實驗室方法
    新增了實驗室數據的處理程式
2023-02-18 應變歸實驗
2023-05-13 新增應變規從端
2023-06-27 新增TBI demo
2023-08-21 8/21
    到底要不要結案幹
